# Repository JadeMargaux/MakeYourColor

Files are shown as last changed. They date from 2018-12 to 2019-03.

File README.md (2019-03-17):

# MakeYourColor

Avec ce projet, nous cherchons à automatiser et donc faciliter la préparation d’une palette de peinture, à l'aide d'une connexion Bluetooth et d'une LED informative. 

Dans l’idéal notre projet est de proposer deux possibilités pour le choix des couleurs : 

•	D’une part via des boutons prédéfinis correspondant à des couleurs précises.

•	D’autre part à l’aide de trois curseurs pour permettre à l’utilisateur une couleur sur mesure. 
 
Ce projet est destiné à un public particulier, comme des écoles maternelles ou des centres aérés.

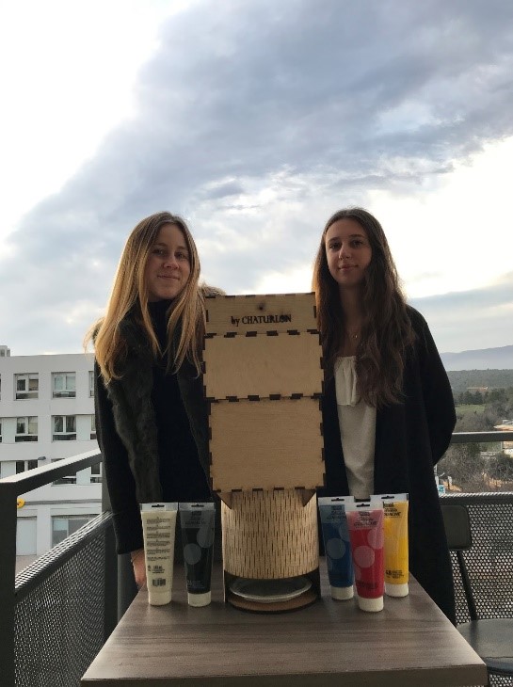
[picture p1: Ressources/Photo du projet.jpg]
Photo du projet


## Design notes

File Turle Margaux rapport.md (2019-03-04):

Turle Margaux                                               

Rapport

Séance 1 : 10 Décembre 2018    

Lors de cette première séance, nous avons commencé par créer un compte github. Nous avons ensuite écrit notre cahier des charges afin de 
définir notre projet (make your color), ainsi que le matériel que nous allons utiliser pour sa réalisation et la répartition des tâches.

De mon côté, j'ai fait sur excel un diagramme de gantt afin de prévoir les tâches à réaliser lors de chaque séance, ce qui est 
nécessaire à l'avancée du projet. 

Diagramme de Gantt

Séance 2 : 17 Décembre 2018

Aujourd'hui, j'ai réalisé le schéma de notre projet afin d'avoir une idée des différentes pièces à modéliser sur inventor. Pour cela, j'ai mesuré toutes les pièces (pipette, moteur). Dans le socle, je vais donc effectuer 5 trous de 4.5 cm de diamètre (diamètre correspondant à celui de la pipette). Notre socle mesurera 20 cm de diamètre et 46.5 cm de hauteur. En bas du socle, je vais faire un trou de largeur 5cm et d'une longueur d'un peu moins de la moitié du périmètre (environ 31cm) du cercle, soit 25 cm où nous allons placer la palette. En haut du socle, je ferais un petit trou dans lequel la barrette avec les dents pourra sortir.
Au dessus de chaque pipette, on aura un moteur avec une roue dentelée et une barrette avec des dents, ce qui permettra de pousser la peinture vers le bas. Il faudra donc modéliser 5 roues et 5 barrettes sur inventor et chercher s'il y a des plans déjâ réalisés sur internet.

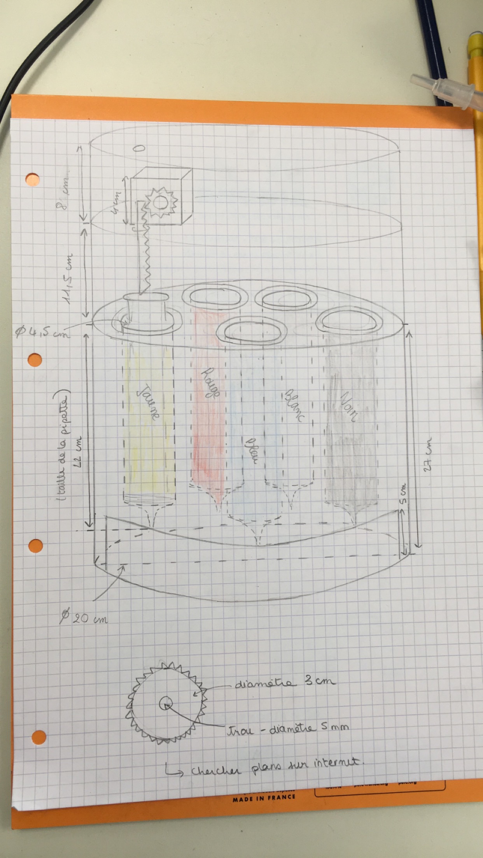
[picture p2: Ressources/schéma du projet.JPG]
Schéma du projet


Séance 3 : 07 Janvier 2019

Aujourd'hui, suite à votre demande, j'ai modifié le diagramme de gantt. En effet, j'ai précisé sur celui-ci notre rôle dans chacune des tâches à réaliser (voir légende).

Ensuite, je me suis intéressée aux différents liens que M.Masson nous a envoyé par mail afin de choisir la forme de la crémaillère. Nous allons en prendre une déjà toute faîte, ce qui est donc la solution la plus simple, qui va nous faire gagner du temps. https://www.stlfinder.com/model/linear-paintbrush-mechanism-nema17-bazykZqV/8073680

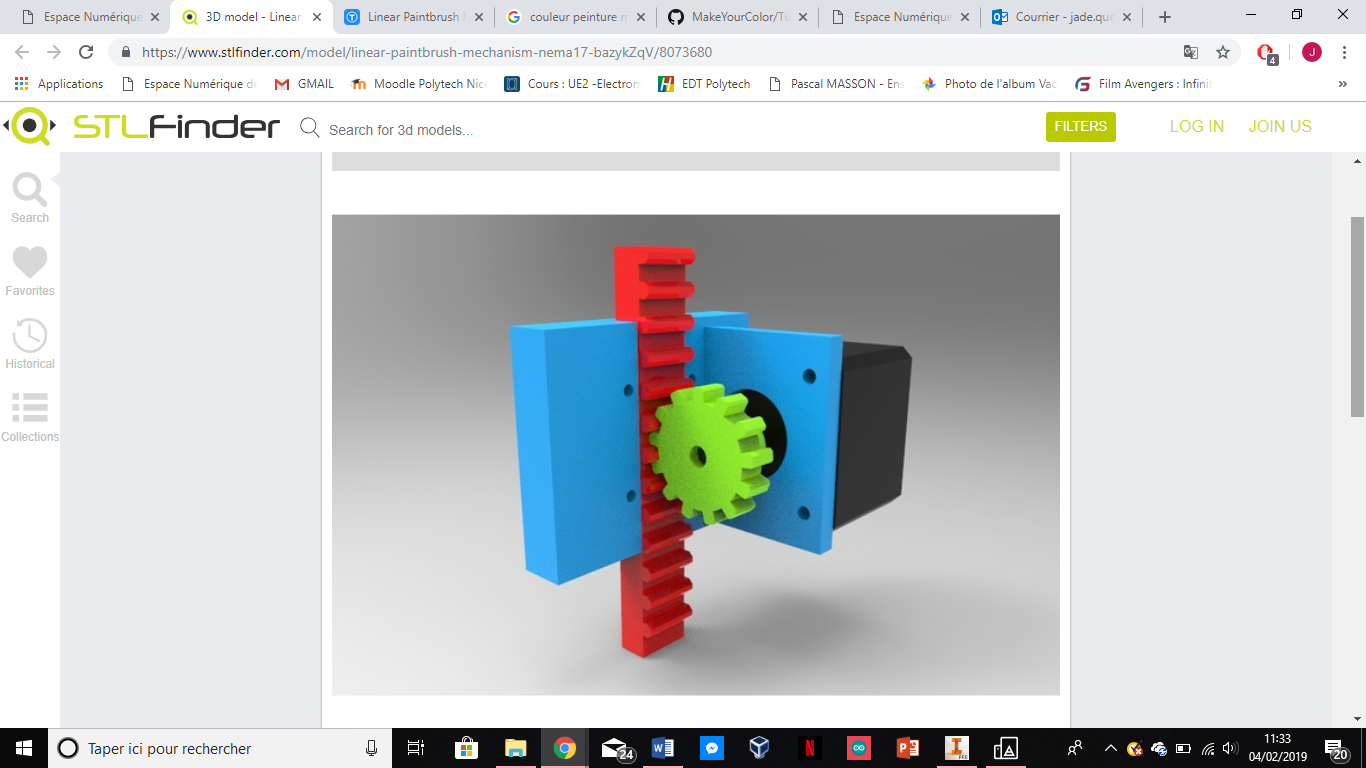
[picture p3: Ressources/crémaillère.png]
crémaillère


Enfin, sur inventor, j'ai commencé à modéliser la pièce centrale du projet, où j'ai percé les différents trous. Je finirai donc la semaine prochaine de modéliser les pièces restantes.

De plus, j'ai aidé jade à faire la soudure des moteurs, en tenant les fils afin que ce soit plus simple pour elle de souder et en dénudant les fils.

Séance 4 : 14 Janvier 2019

Aujourd'hui, j'ai dénudé les fils, et je les ai tenus pour la soudure du dernier moteur.
J'ai fini de modéliser les deux premières pièces de notre projet sur inventor, que vous pouvez voir ci-dessous. Il me restera donc à modéliser la dernière pièce puis à les imprimer en 3D, et les coller.
De plus, j'ai aidé jade à savoir si les moteurs tournaient lorsqu'elle appuyait sur les boutons via le téléphone portable.
Oral de fin de séance.

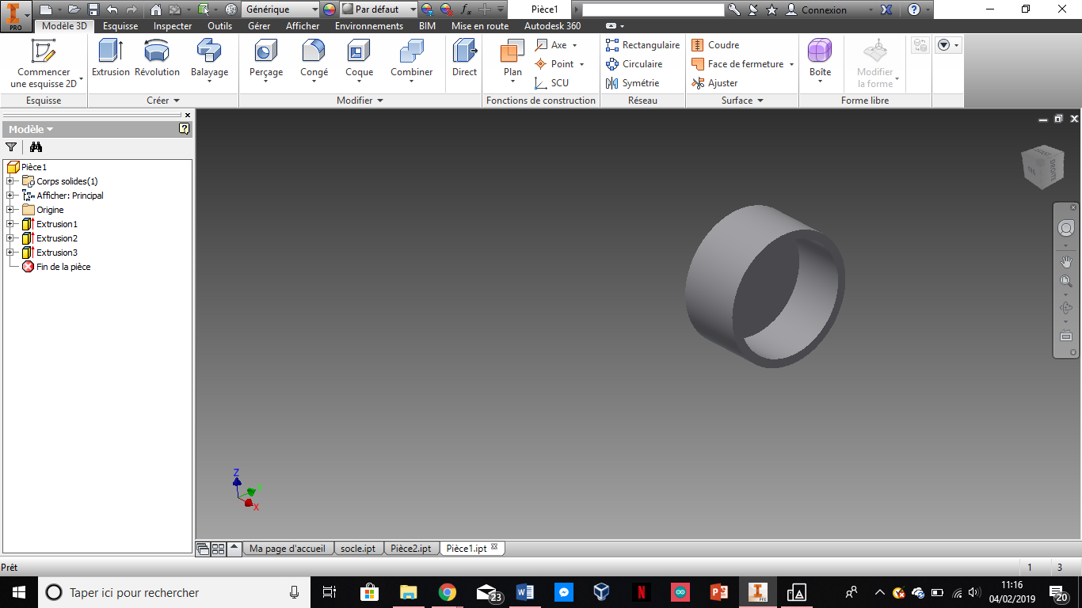
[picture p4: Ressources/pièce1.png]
pièce 1


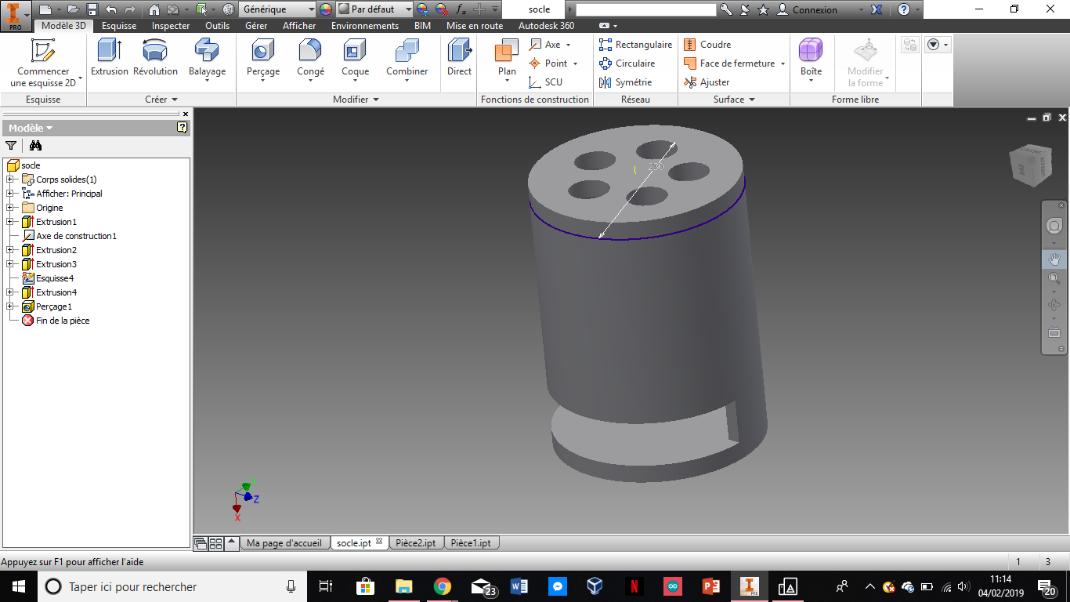
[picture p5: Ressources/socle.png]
socle

                                                                                               
                                                                                         

Séance 5 : 04 Février 2019

Aujourd'hui, nous avons réalisé la soudure du dernier moteur.
J'ai recherché sur internet une palette de couleurs plus complète que nous allons faire à partir des couleurs que nous avons déjà créées.

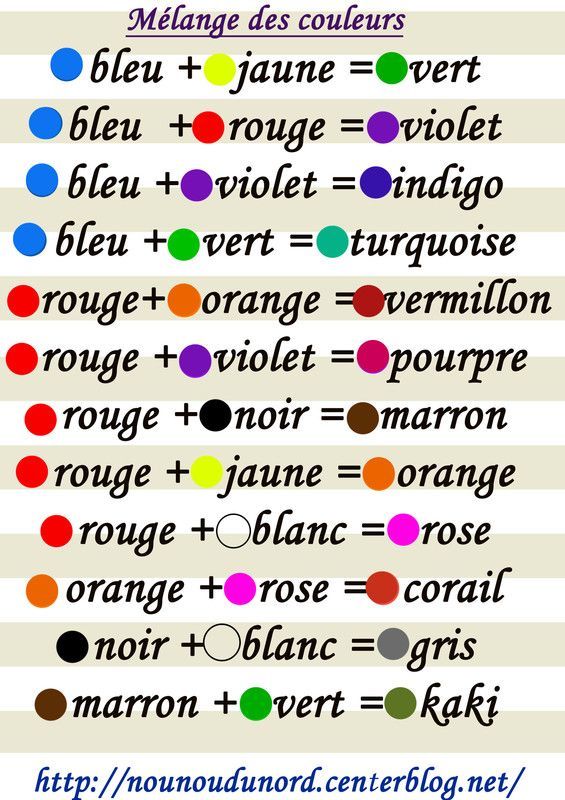
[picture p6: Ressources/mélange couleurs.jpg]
mélanges couleurs


Ensuite, j'ai modélisé sur inventor, la dernière pièce (celle du dessus), que vous pouvez voir ci-dessous

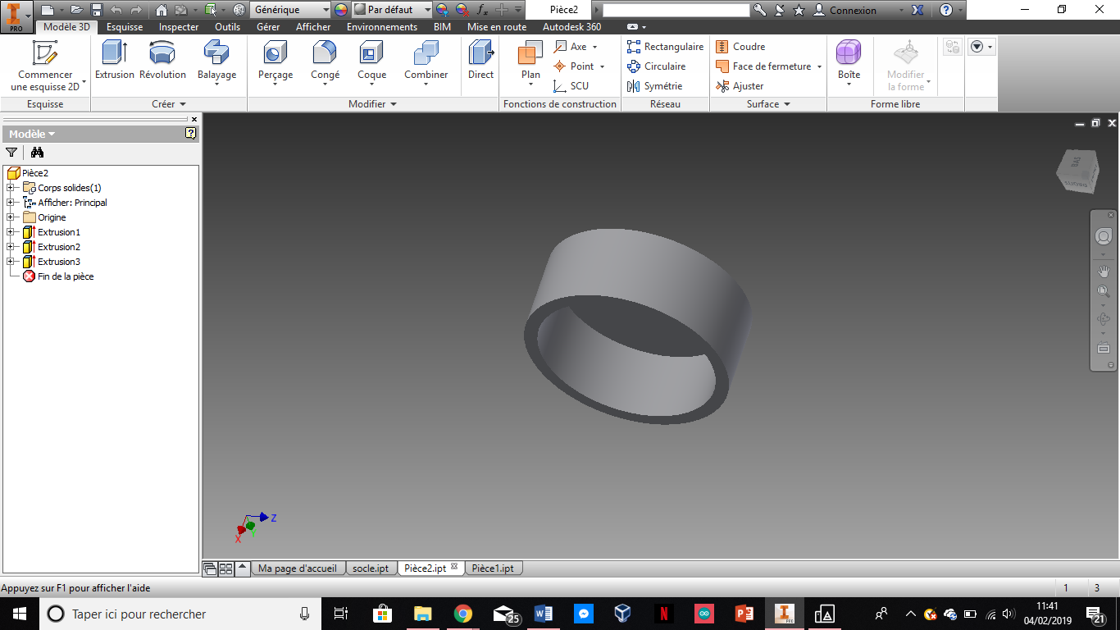
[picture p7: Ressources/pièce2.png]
pièce 2


Enfin, nous sommes allées au fablab afin d'imprimer les différentes pièces que j'ai modéliser.
Malheureusement, étant donné que notre socle ait une hauteur de 27cm, ceci est beaucoup trop grand pour l'imprimante 3D. Nous avons donc fait un choix entre imprimer le socle en 3D mais en deux fois et le coller ou faire notre socle en bois et découper les différentes pièces à l'aide du laser. Nous avons choisi, avec les conseils de la personne en charge du fablab d'avoir un socle en bois. Or, il faut savoir que pour découper les pièces de bois, il faut des plans en 2D alors que j'avais déjà réalisé tous les plans en 3D. J'ai donc redessiner les différents plans en 2D que nous avons refait sur le logiciel inscape. 

Jeudi 07 Février 2019

Nous avons réalisé puis découpé au laser un grand rectangle de 27 cm de hauteur et 62.8cm de largeur, avec plusieurs striures pour coller ses deux extrémités afin de former un cylindre. Au premier essai, les colonnes avec les différents traits pour les striures étaient espacées de 1.6cm ce qui était beaucoup trop grand pour pouvoir "plier" le bois. Au deuxième essai, nous avons donc espacé les colonnes d'environ 4mm, ce qui nous a permis de bien relier les deux extrémités du rectangle (45min de découpe). Ensuite, nous avons découper deux cercles de diamètre 188mm : le premier étant le socle sur lequel nous allons positionner le cylindre et le deuxième cercle, lui-même composé de cinq cercles pour y mettre les cinq seringues. (Au premier essai de découpe de cercle, nous avions découpé un cercle de 192mm, ce qui était beaucoup trop grand par rapport à la base de notre cylindre. Nous avions donc calculer l'écart entre les deux extrémités du rectangle lorsque nous essayions de les relier : 1.5cm, que nous avons retiré au périmètre du cercle du cylindre que nous avions tracé sur une feuille, afin de calculer le nouveau diamètre). Finalement nous avons collé la partie supérieur du cylindre avec le rectangle, que nous avons accroché avec l'aide d'une sangle.

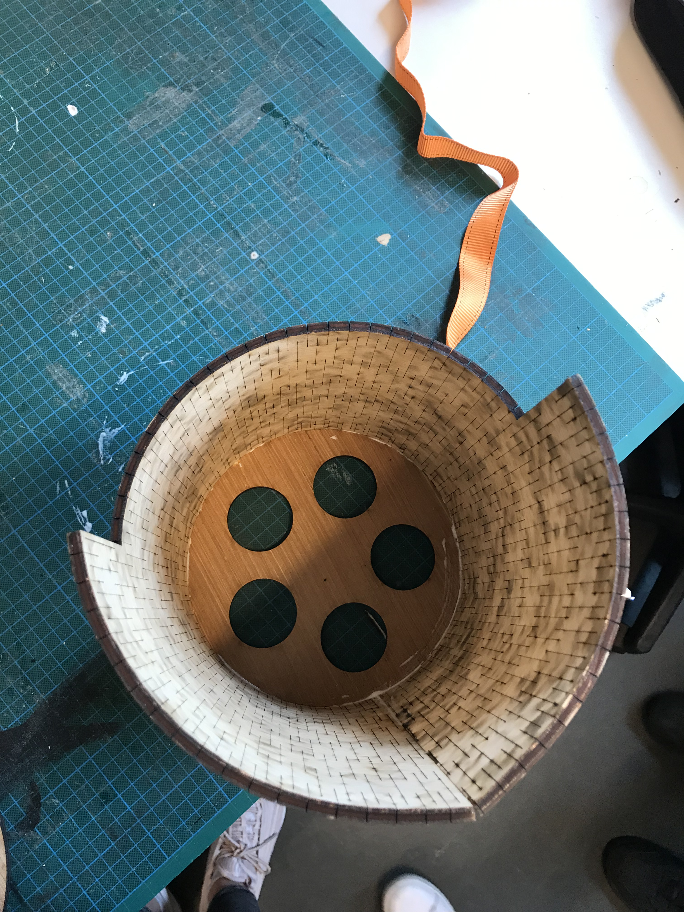
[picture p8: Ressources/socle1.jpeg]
photo collage1


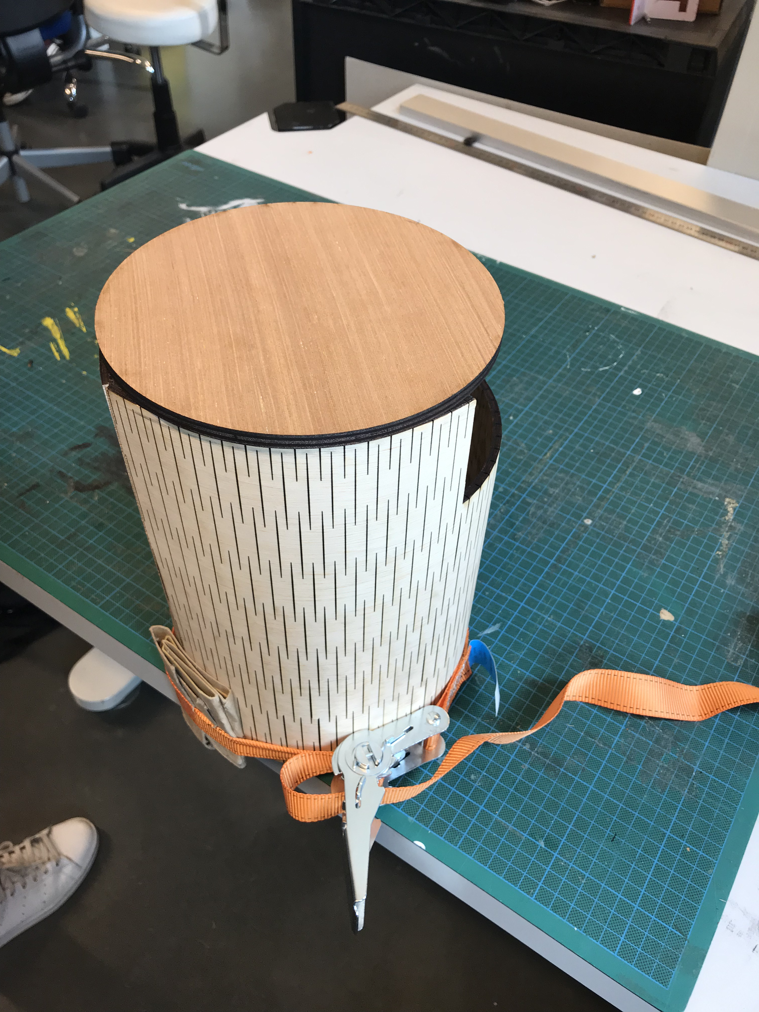
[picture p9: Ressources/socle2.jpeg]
photo collage2


Vendredi 08 Février 2019

Aujourd'hui, nous sommes allées au fablab. J'ai redessiné les plans de notre projet car nous nous sommes rendues compte que le schéma de base n'était pas pratique car, du fait que les trois cylindres soient collés, nous ne pouvions pas recharger la peinture dans les seringues. Nous avons donc décidé d'améliorer ce point. Pour cela, nous avons choisi de faire un cube, avec un trou d'un diamètre un plus grand que le cylindre pour qu'ils puissent s'emboiter. Nous allons faire tenir le cube avec des sortes d'equerres de fixation, sur lequel celui sera posé. On pourra donc enlever le cube du cylindre pour prendre les seringues et les recharger lorqu'elles sont vides.

Modélisation de la boîte grâce à :
http://carrefour-numerique.cite-sciences.fr/fablab/wiki/doku.php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

Après avoir refait le schéma du projet, nous avons collé la partie inférieur du cylindre. Ensuite, nous avons découpé les 6 faces du cube à la découpeuse laser, dans une des faces, nous avons découpé un cercle d'un diamètre un peu plus grand que celui du cylindre.
Enfin, nous avons collé les différentes faces du cube.

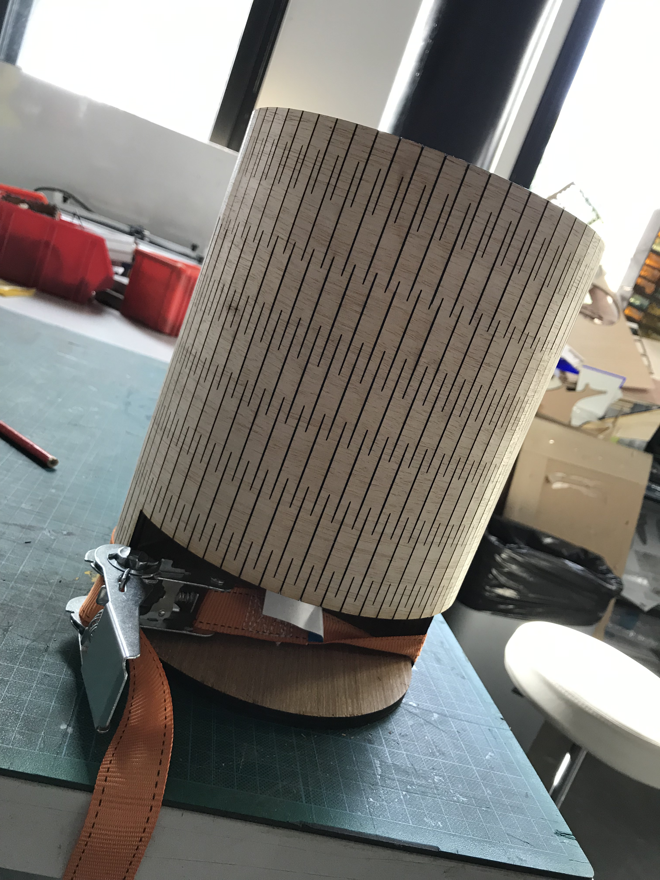
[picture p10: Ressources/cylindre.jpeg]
cylindre


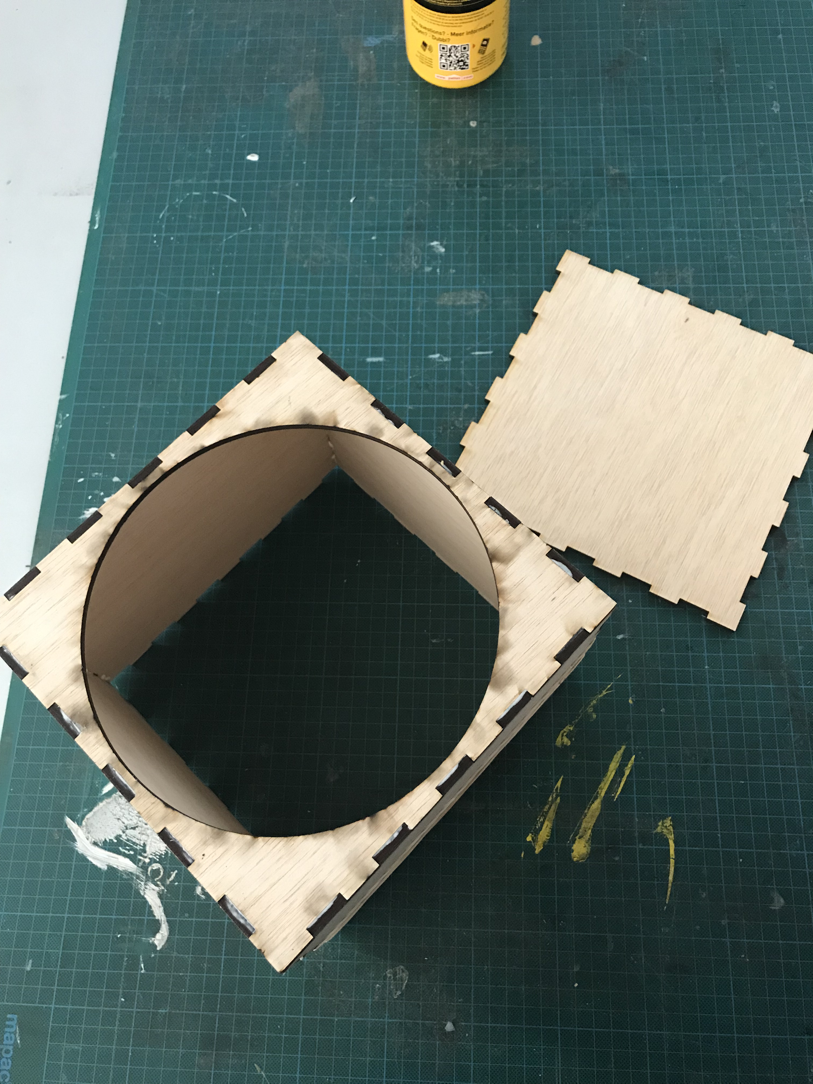
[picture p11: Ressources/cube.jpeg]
cube


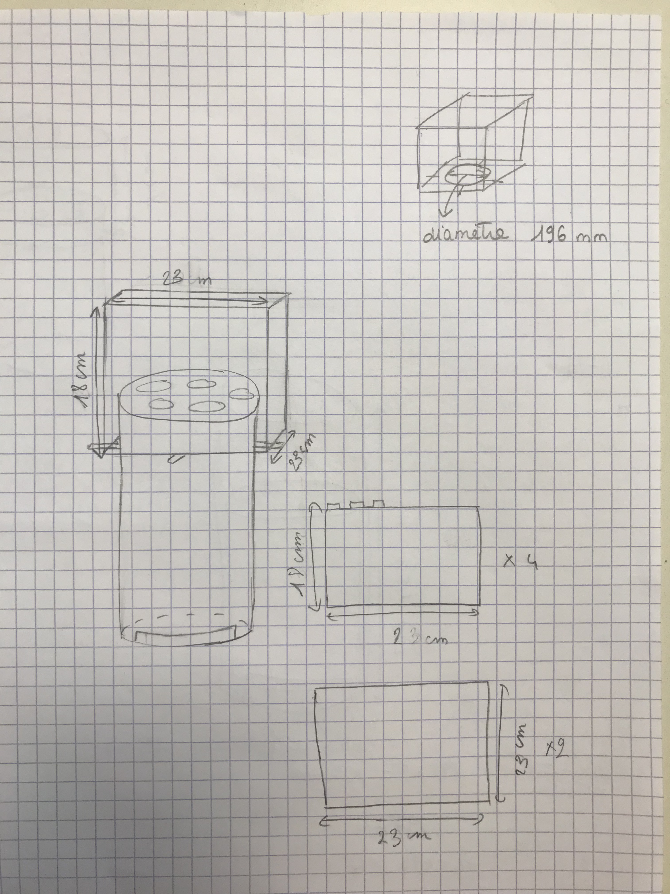
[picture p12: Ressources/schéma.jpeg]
schéma


Séance 6 : 11 Février 2019

J'ai recherché et j'ai trouvé, sur ebay, les peintures que nous allons utiliser. Il s'agit de 5 tubes de gouaches de 220ml (les couleurs primaires : rouge, bleu et jaune et noir et blanc).
Nous sommes allés au fablab pour faire à la découpeuse la partie supérieure de notre projet. Il sagit d'un parallélépipède où nous fixerons par la suite les moteurs. De plus nous avons découpé au laser 4 petites équerres que nous avons collés sur le cylindre. Ces équerres permettront de faire tenir la boite sur le cylindre. Cette boîte ne sera pas collée sur les équerres afin de pouvoir la retirer pour prendre seringues et les remplir lorsqu'elles seront vides.

La prochaine fois que nous irons au fablab, il faudra s'occuper des engrenages.

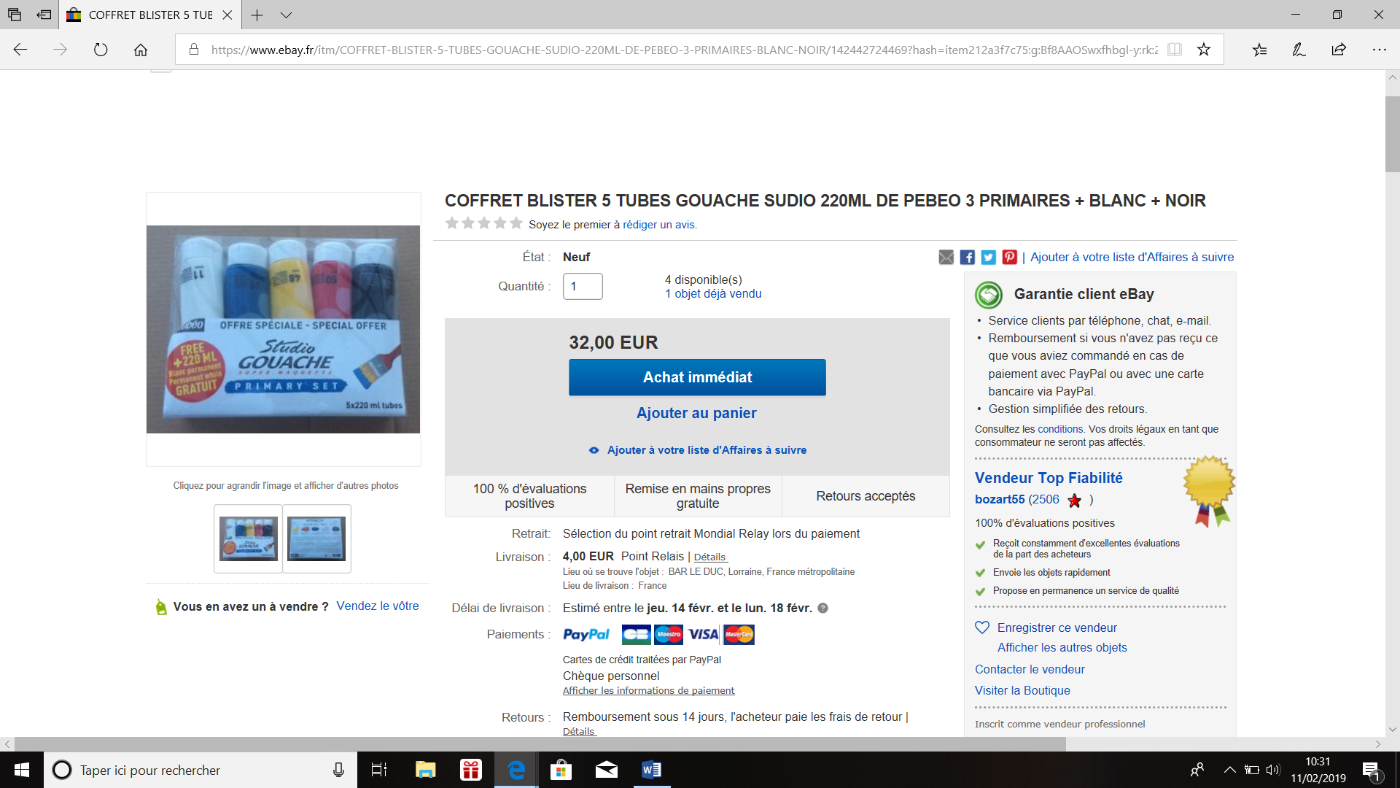
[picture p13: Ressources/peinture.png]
commande

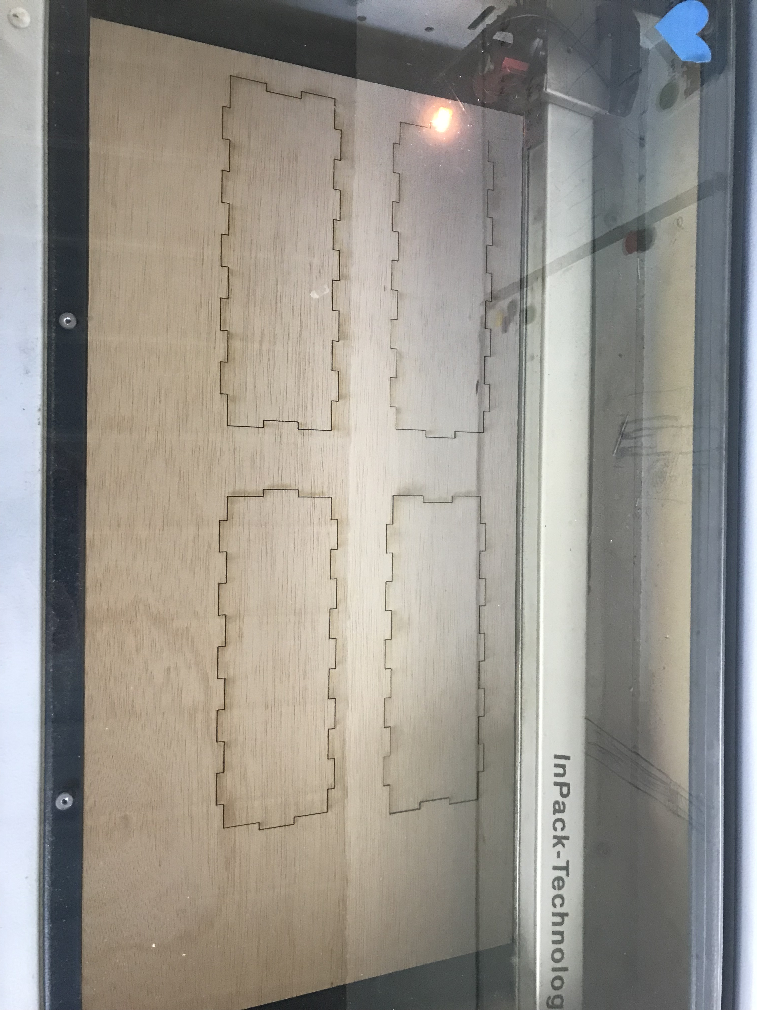
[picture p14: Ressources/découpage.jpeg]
découpage

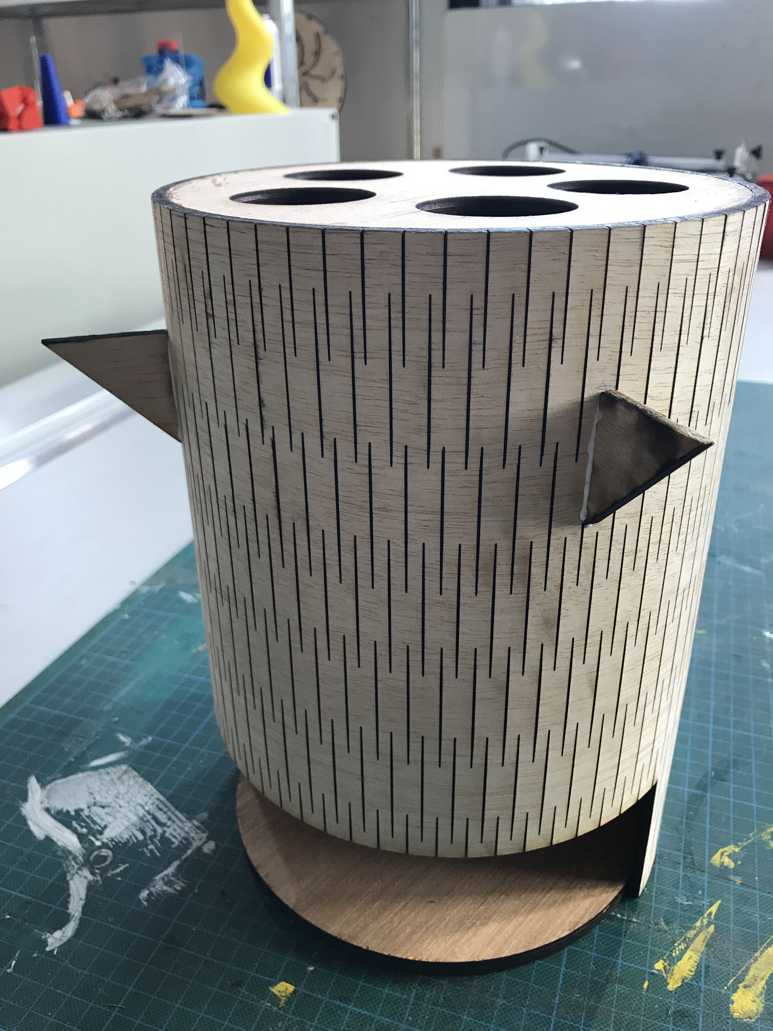
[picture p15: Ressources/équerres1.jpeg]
équerres

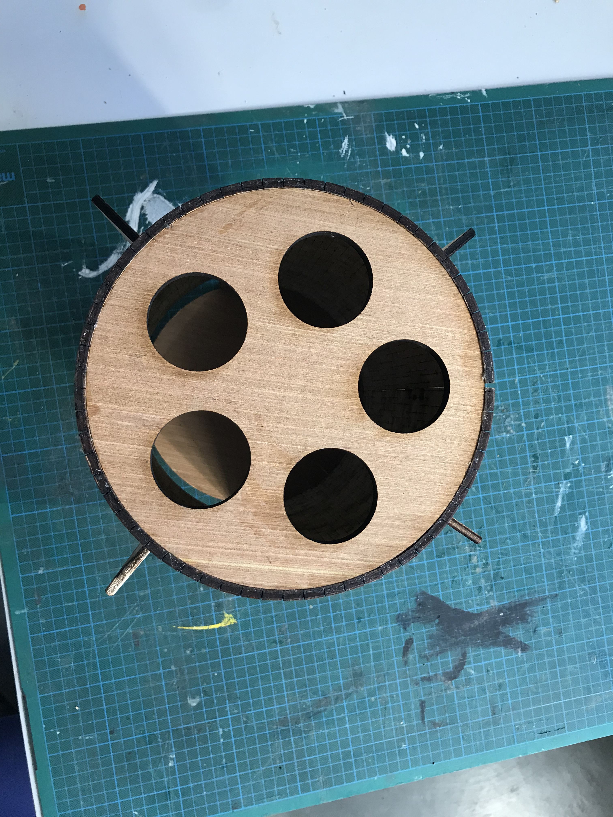
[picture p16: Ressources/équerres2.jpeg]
équerres


Séance 7 : 25 Février 2019

Aujourd'hui, j'ai travaillé avec jade sur le codage. En effet, nous avons réussi avec l'aide de Mr. Masson, à faire en sorte que la led s'allume en fonction de la couleur choisie par les curseurs rouge vert et bleu ou en fonction des boutons où nous avons déjà défini une couleur (orange, marron, rose, rouge, bleu, jaune, vert, noir, blanc, gris, violet). La couleur choisie par l'utilisateur sera ainsi visible sur la led. L'utilisateur pourra modifier sa couleur tant qu'il n'aura pas appuyé sur le bouton start. Il nous restera donc à faire le codage du bouton start pour valider le choix de l'utilisateur. De plus, nous avons vérifié si les bons moteurs tournaient lorsque nous appuyons sur la couleur correspondante. Cependant nous avons eu un problème puisque de la fumée est sortie des fils lorsque nous testions les moteurs. Puis, les moteurs ne marchaient plus.

Jeudi 28 Février 2019

Nous sommes allées au fablab pour imprimer en 3D la crémaillère. Sur ce que nous a envoyé Mr. Masson, les dimensions ne pouvaient pas être modifiés. Or la barette sur le site mesure 10cm et nous voulions une barette de 20 cm. Nous avons donc imprmer la barette de 10cm sur laquelle nous rajouterons une cale. Suite à la première impression (3h34), la barette était beaucoup trop large et ne pouvait pas glisser dans le dispositif prévu à cet effet. Nous avons donc mesuré l'écart entre le dispositif et la barette et nous avons réimprimer une barette à la bonne largeur. Celle-ci glissait alors correctement sur le montage. Il nous restera à imprimer les quatre autre crémaillères pour les quatre autres moteurs puis à les coller sur la structure. De plus, il nous restera à faire les cales. 

(14.7/15=0.98mm)

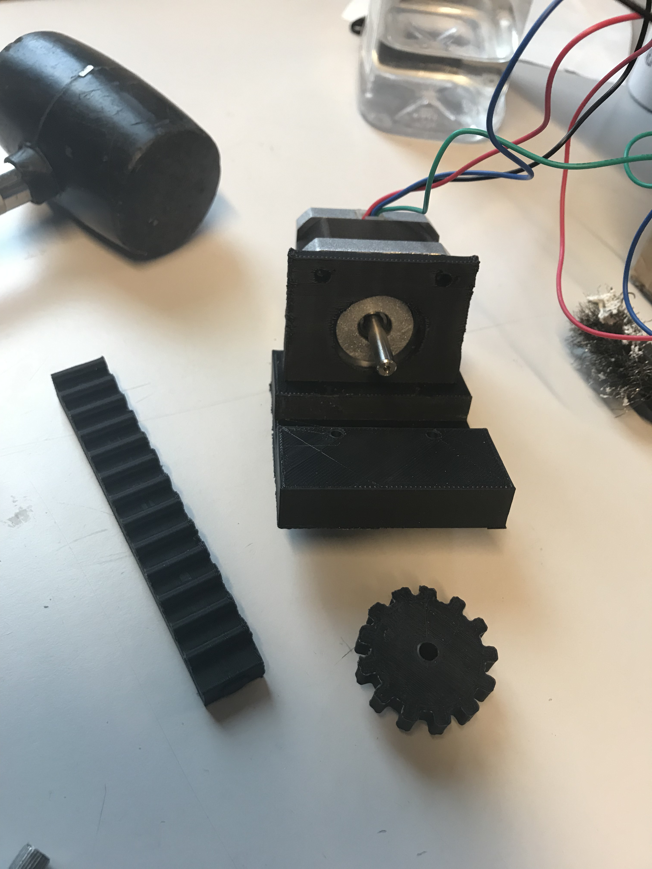
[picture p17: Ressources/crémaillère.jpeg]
crémaillère


Séance 8 : 04 Mars 2019

Nous avons dû avec l'aide de Mr. Masson vérifier si tous les moteurs tournaient correctement suite au court-circuit de la semaine précédente. De plus nous avons fini le programme concernant la led, qui s'allume en fonction des boutons ou des curseurs. Il nous reste par conséquent à faire le programme du bouton start et à trouver une solution pour passer des couleurs des curseurs en RGB (synthèse additive) aux couleurs primaires en peinture (rouge, jaune, bleu), ce qui est plutôt compliqué.

Recherche:
http://comment-peindre.com/couleurs-primaires-pour-debuter/

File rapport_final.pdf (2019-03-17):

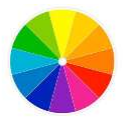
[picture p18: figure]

Ecole Polytechnique Universitaire de Nice Sophia-Antipolis, Département électronique

1645 route des Lucioles, Parc de Sophia Antipolis, 06410 BIOT

## PROJET Arduino - Peip2

### Année scolaire 2018-2019

# Make your color

## Étudiants : Queffeulou Jade Turle Margaux

## Encadrant : Masson Pascal

Ecole Polytechnique Universitaire de Nice Sophia-Antipolis, Département électronique

## Remerciements

Nous tenons à remercier dans un premier temps, l’équipe pédagogique de Polytech Nice-Sophia et les intervenants professionnels responsables de la formation de deuxième année de Peip, pour avoir assuré la partie théorique en amont du projet.

Nous remercions Monsieur Masson, professeur d’électronique et son stagiaire, pour l’aide et les conseils concernant les missions évoquées dans ce rapport qu’ils nous ont apporté lors des différentes étapes du projet.

En dernier lieu, nos remerciements vont à Monsieur Marc Forner, fabManager, qui a été présent tout au long de la conception de notre structure et nous a particulièrement aidé pour l’impression des pièces.

Ecole Polytechnique Universitaire de Nice Sophia-Antipolis, Département électronique

### Sommaire

II- Présentation du matériel | 6-7
III.2 Partie construction | 9-10

Ecole Polytechnique Universitaire de Nice Sophia-Antipolis, Département électronique

Introduction

Avec ce projet, nous cherchons à automatiser et donc faciliter la préparation d’une palette de peinture.

L’idée est de mettre en place un distributeur de peinture. La peinture est contenue dans des seringues. Pour ce projet, cinq seringues sont nécessaires. Elles correspondent aux trois couleurs primaires : rouge, bleu et jaune ainsi que le noir et le blanc. Le distributeur permet également de créer de nouvelles couleurs à l’aide des couleurs contenues dans lesdites seringues. Tout cela contrôlable depuis une application mobile connectée par Bluetooth. Le choix de ce module permet à l’utilisateur de se connecter facilement à la machine.

Dans l’idéal notre projet est de proposer deux possibilités pour le choix des couleurs :
- D’une part via des boutons prédéfinis correspondant à des couleurs précises.
- D’autre part à l’aide de trois curseurs pour permettre à l’utilisateur une couleur sur mesure.

Ce projet est destiné à un public particulier, comme des écoles maternelles ou des centres aérés.

Ecole Polytechnique Universitaire de Nice Sophia-Antipolis, Département électronique

I- Objectifs

I.1- Objectifs initiaux

Notre projet a pour but de créer différentes couleurs à l’aide de moteurs sur lesquels sera fixée une roue dentelée. Lorsque les moteurs seront en marche, ils feront tourner la roue qui va elle-même faire coulisser une crémaillère. Cette crémaillère va pousser sur les seringues, ce qui va faire tomber la peinture sur la palette et créer une nouvelle couleur.
Les moteurs seront eux-mêmes actionnés grâce au module Bluetooth par différents boutons qui définissent une couleur particulière, présents sur l’application mobile.

Ces boutons pourront actionner les couleurs suivantes :
- orange (mélange de rouge et de jaune)
- violet (mélange de bleu et de rouge)
- vert (mélange de jaune et bleu)
- marron (mélange de rouge, jaune et bleu)
- rose (rouge et blanc)
- gris (noir et blanc)

Ainsi que les couleurs déjà présentes dans les seringues :
- rouge
- jaune
- bleu
- noir
- blanc

De plus, initialement, le projet avait également pour but d’éclaircir (respectivement assombrir) les couleurs, en ajoutant au mélange la couleur blanche (respectivement noire).

Ecole Polytechnique Universitaire de Nice Sophia-Antipolis, Département électronique

I.2 Objectifs atteints

Finalement, nous avons abandonné l’idée d’éclaircir ou d’assombrir les couleurs en y ajoutant du blanc ou du noir. Il suffira simplement d’appuyer de nouveau sur le bouton blanc pour éclaircir ou noir pour assombrir.

En plus des boutons correspondants à des couleurs particulières, l’application sera constituée de trois curseurs : cyan, magenta et jaune.
Ces curseurs permettant alors à l’utilisateur de créer sa propre couleur. Cette couleur ainsi créée pourra être visible sur une LED et modifiable tant que l’utilisateur n’aura pas appuyé sur le bouton start.

De plus, par soucis de praticité, la forme de la structure n’est plus la même que sur le schéma initial (cf annexe).

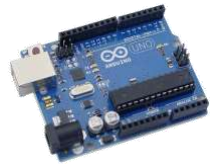
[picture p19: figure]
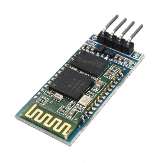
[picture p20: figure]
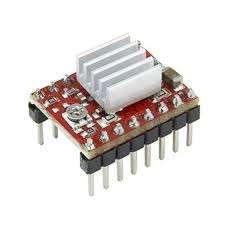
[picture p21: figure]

Ecole Polytechnique Universitaire de Nice Sophia-Antipolis, Département électronique

II- Présentation du matériel

Carte Arduino
ATmega328PB
Xplained mini

⇨ Gère l’ensemble de
l’électronique

Moteur pas à pas
Nema 17

⇨ Fait tourner la roue dentelée

Driver A4988
avec radiateur

⇨ Contrôle le moteur pas-à-pas

Module Bluetooth HC-06

⇨ Permet la connexion Bluetooth avec l’application “Bluetooth Electronics” sous Android

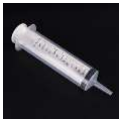
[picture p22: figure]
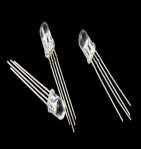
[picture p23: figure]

Ecole Polytechnique Universitaire de Nice Sophia-Antipolis, Département électronique

Seringue 150 ml

⇨ Contient la peinture

LED RGB branchée en anode

⇨ informer l’utilisateur de la couleur créée

Condensateur électrolytique bleu isolé

⇨ permet de lisser la tension

Ecole Polytechnique Universitaire de Nice Sophia-Antipolis, Département électronique

III- Réalisation

III.1 Partie code

La partie code du projet se décompose en plusieurs codes distincts.

La première étape est la connexion avec le module Bluetooth : il y a un code qui permet à l’utilisateur de se connecter via le module Bluetooth HC-06 à l’application “Bluetooth Electronics” du mobile. Il faut alors que l’utilisateur tape les commandes AT+Namenom et AT+PINpin sur le moniteur série pour pouvoir se créer un identifiant pour la toute première fois. Cette connexion ayant été préalablement faite, l’utilisateur n’a plus qu’à, chaque fois, se reconnecter avec le même identifiant sur l’application.

La deuxième étape est le choix de la couleur personnalisée :

Dans ce cas, la carte Arduino est en dialogue avec le module Bluetooth.
Les trois curseurs ; cyan, magenta et jaune ainsi que les boutons sont définis à l’aide de la fonction Switch(). En effet, les trois curseurs et les onze boutons correspondant à une couleur déjà définie sont associés à des lettres différentes. Lorsque la lettre correspondant à une couleur est envoyée à la carte Arduino, cette couleur est alors visible sur la LED.

Ainsi, sur l’application, l’utilisateur peut créer sa propre couleur avec les curseurs en la visualisant sur la LED RGB. Ce processus se fait via la fréquence du PWM qui est envoyé par l’application Bluetooth. Cette fréquence prend des valeurs entières allant de 0 à 255 et suivant la valeur de la fréquence PWM la couleur diffère.

La dernière étape correspond au fonctionnement des moteurs :

Une fois la couleur réalisée par l’utilisateur, il peut la valider grâce au bouton START présent également sur l’application. Ce bouton est lui aussi relié à une lettre. Son utilisation permet aux moteurs correspondants de se mettre en marche. En effet, chaque couleur créée correspond à trois valeurs de PWM différentes en simultanée. Par exemple le rouge à pour valeurs (0,255,0). Ces trois valeurs correspondent aux trois couleurs que sont le cyan, magenta et jaune. Ainsi les valeurs du PWM de la couleur entraîne le fonctionnement des moteurs dont le pas correspond à cette même valeur.

Ecole Polytechnique Universitaire de Nice Sophia-Antipolis, Département électronique

Pour pouvoir vérifier le fonctionnement de chaque élément, il y a deux codes de bases, extérieur au code final. Parmi ces 2 codes, on trouve : le code de rotation d’un moteur pas-à-pas, qui gère le fonctionnement d’un unique moteur, et le code de la LED RGB. Ce dernier a été nécessaire pour déterminer les bonnes valeurs du PWM à utiliser.

Les codes sont visibles dans la partie Annexes.

III.2 Partie construction

Toute la partie construction de la structure s’est déroulée au fablab de Polytech Nice Sophia grâce à la découpeuse laser et l’imprimante 3D.

Nous avons construit l’intégralité de notre structure. Celle-ci se compose en quatre parties principales :

La partie inférieure, de forme cylindrique.
La réalisation de ce cylindre s’est faîte à partir : d’un grand rectangle de bois de 27 cm de hauteur et 62.8 cm de largeur, striés, afin de pouvoir lui donner de la souplesse et coller les deux extrémités, ainsi que de deux cercles. Ces deux cercles ont pour diamètre 188mm : le premier étant le socle sur lequel nous allons positionner le cylindre et le deuxième est lui-même composé de cinq cercles pour y mettre les cinq seringues. Le tout collé et maintenu pendant un certain temps avec une sangle.

La partie centrale, une boîte.
Ce cube est composé de quatre rectangles de longueur 18 cm et de largeur 23 cm ainsi que deux carrés de largeur 23 cm. La face inférieure de la boîte possède un trou d'un diamètre un peu plus grand que celui du cylindre pour qu'ils puissent s'emboîter. Ainsi, on pourra retirer la partie supérieure de la structure pour retirer les seringues du cylindre et les recharger lorsqu’elles sont vides. Tandis que la face supérieure possède 5 trous (de 2,3 cm x 4,5 cm) au-dessus de chaque piston afin de laisser passer la crémaillère.
Ce cube est donc emboîté et tient sur la partie inférieure grâce à des sortes d'équerres de fixation, sur lequel celui-ci sera posé.

Puis, au-dessus de cette boîte, il y a une seconde boîte composée de quatre rectangles de mesure 12,5 cm x 23,5 cm et de deux carrés de longueur 23,5 cm.

Ecole Polytechnique Universitaire de Nice Sophia-Antipolis, Département électronique

C’est à l’intérieur de cette boîte que sont fixés les cinq moteurs au-dessus des cinq seringues avec du scotch double face. Afin que les crémaillères puissent pousser les pistons et ainsi faire tomber la peinture dans la palette, il y a cinq trous de 2,3 cm x 4,5 cm sur la face inférieure. De plus, sur la face supérieure, il y également cinq trous de même dimension que précédemment pour faire passer les fils vers la partie supérieure de la structure.

La partie supérieure, une troisième boîte.
Cette boîte mesure 8 cm x 23 cm x 23 cm. La face inférieure possède aussi cinq trous (toujours de même dimension) afin de pouvoir connecter les moteurs à la plaque Arduino qui se trouve dans cette boîte. De plus, sur la face avant, nous avons écrit avec la découpeuse laser : “by CHATURLON” et nous avons découpé un trou au-dessus afin que la LED puisse être visible des utilisateurs.

En dernier lieu, l’imprimante 3D nous a permis d’imprimer le mécanisme composé du support du moteur ainsi que la crémaillère et la roue dentelée afin de faire fonctionner l’ensemble.

IV. Difficultés

IV.1 Partie code

Au début, le code était unique. Il permettait la rotation des moteurs lorsque l’utilisateur appuie sur les boutons prédéfinis. À la suite de la première présentation orale, le professeur a mis en avant la simplicité du projet. Ainsi, il a été décidé d’ajouter des curseurs pour la création de couleur personnalisées et une LED RGB pour visualiser la couleur choisie. Cette partie étant plus complexe, les premiers essais n’étaient pas fluctuants. En effet, la LED RGB branchée en anode donnait des couleurs cyan, magenta et jaune. Cela s’explique par le fait que les valeurs de la fréquence PWM sont en réalité inversées, c’est à dire que le(0,0,0) donne la couleur blanche tandis que le (225,255,255) donne la couleur noire. Il a donc fallu faire attention d’écrire les bonnes valeurs de PWM correspondantes dans le nouveau code. Cependant, après réflexions, la synthèse soustractive fournie par le cyan, magenta et jaune semble plus proche des couleurs primaires de la peinture que la synthèse additive fournie par le rouge, vert et bleu. Nous avons donc gardé les valeurs de base.

Ecole Polytechnique Universitaire de Nice Sophia-Antipolis, Département électronique

De plus, l’un des drivers A4988, est devenu défectueux. Les moteurs tournaient, enfin vibraient sans arrêt et le moteur connecté au driver ne tournait plus du tout. Cela produisait une sorte de court-circuit. Pendant les essais, il y avait une forte surchauffe. Il nous a donc fallu un nouveau driver. D’ailleurs, pour éviter encore plus une surchauffe des moteurs, nous avons défini l’entrée “enable” qui met les moteurs à l’arrêt quand ils ne sont pas utiles.

IV.2 Partie construction

Pour commencer, la structure était modélisée sur Inventor afin de l’imprimer en 3D, cependant pour des raisons de dimension, il n’était pas possible d’utiliser l’imprimante. En effet, la partie inférieure mesurant 27 cm de hauteur, ceci était beaucoup trop grand à imprimer. Finalement, pour palier à ce problème, nous avons décidé d’utiliser la découpeuse laser et ainsi d’avoir une structure en bois. Tous les plans ont donc été refait en 2D avec le logiciel Inkscape avec l’aide de la personne en charge du fablab.

Pour ce qui est de la partie inférieure, nous avons dû faire plusieurs stries sur le rectangle de bois afin de pouvoir le plier. Or, au premier essai, celles-ci étaient beaucoup trop écartées (1,6 cm), ce qui rendait impossible le pliage du bois. Au deuxième essai, l’écart choisi entre les stries était beaucoup plus petit (4 mm), ce qui nous a permis de bien relier les deux extrémités du rectangle.

Ensuite, le schéma de base n'étant pas pratique, du fait que les trois cylindres soient collés, la peinture dans les seringues ne pouvait pas être rechargée. Notre structure a dû être modifié. En effet, la structure finale ne correspond pas à celle sur le schéma initial. Au départ, celle-ci devait être un cylindre composé de trois parties cylindriques collées entre elles mais finalement, elle est composée d’un cylindre et de trois boîtes. Les trois boîtes sont collées entre elles et peuvent être retirées du cylindre afin de pouvoir prendre les seringues pour les recharger.

Enfin, pour l’impression 3D du mécanisme composé de la crémaillère et la roue dentelée, la longueur de la crémaillère était de 10 cm sur le site trouvé par Mr. Masson et il fallait que celle-ci mesure 20 cm. Nous avons donc gardé celle-ci, car par manque de temps, nous ne pouvions refaire les dimensions. De plus, suite à la première impression du mécanisme (d’une durée de 3h34), la

Ecole Polytechnique Universitaire de Nice Sophia-Antipolis, Département électronique crémaillère était beaucoup trop large et ne pouvait pas glisser dans le dispositif prévu à cet effet. Nous avons donc mesuré l'écart entre le dispositif et la crémaillère et nous l’avons réimprimé à la bonne largeur. Celle-ci glissait alors un peu mieux sur le montage. Cependant ce n’était pas suffisant pour un glissement optimal. En effet, nous avons dû limer la crémaillère ainsi que la roue dentelée car du fait que l’impression 3D n’était pas parfaite, il y avait trop de frottement ce qui empêchait les moteurs de tourner correctement. D’autre part, les trous pour les vis sur le support et le trou central pour faire passer la tige du moteur étaient trop petit donc il a fallu repercer tous les trous de chaque moteur, ce qui nous a pris du temps.

Ecole Polytechnique Universitaire de Nice Sophia-Antipolis, Département électronique

Conclusion

Bilan final du projet : Make your color or not ?

A ce stade, notre projet a partiellement atteint les objectifs que nous avions fixé, même si certains ont été modifié en cours de route.

En résumé, l’utilisateur choisit la couleur qu’il souhaite sur le téléphone grâce aux boutons prédéfinis ou aux curseurs, et la valide grâce au bouton START. Cette couleur est visible à tout moment sur la LED. Le téléphone, lui, est connecté à l’Arduino via un module Bluetooth. Puis il n’a plus qu'à attendre que la peinture contenue dans les seringues coule sur la palette.

C’est une machine qui se veut être pratique, rapide et surtout utile pour les inconnus des couleurs.

D’une part, les difficultés que nous avons rencontrées, ont été en quelque sorte bénéfiques car elles ont permis de rendre la machine plus fonctionnelle. En effet, notre schéma de base n’aurait servi que pour une seule fois. Cependant, à cause de certains problèmes rencontrés, et d’un manque de temps, les tests avec la peinture n’ont pas été réalisés.

Ressenti vis à vis de ce projet :

Nous avions l’habitude de réaliser des exposés ou des présentations sur un sujet précis cependant le fait de créer un projet entièrement, de l’idée à la conception était nouveau pour nous (mis à part le TPE de 1ère).
Les compétences acquises au cours des TD ont pu être utilisées à bon escient. Imaginer un projet, le mettre en oeuvre, palier aux problèmes et pouvoir l’améliorer est une expérience enrichissante.

Ecole Polytechnique Universitaire de Nice Sophia-Antipolis, Département électronique

Ressources

https://www.stlfinder.com/model/linear-paintbrush-mechanism-nema17-bazykZqV/8073680 (https://www.stlfinder.com/model/linear-paintbrush-mechanism-nema17-bazykZqV/8073680)

http://carrefour-numerique.cite-sciences.fr/fablab/wiki/doku.php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 (http://carrefour-numerique.cite-sciences.fr/fablab/wiki/doku.php)

https://www.ebay.fr/itm/COFFRET-BLISTER-5-TUBES-GOUACHE-SUDIO-220ML-DE-PEBEO-3-PRIMAIRES-BLANC-NOIR/142442724469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 (https://www.ebay.fr/itm/COFFRET-BLISTER-5-TUBES-GOUACHE-SUDIO-220ML-DE-PEBEO-3-PRIMAIRES-BLANC-NOIR/142442724469)

https://www.arduino.cc/reference/en/language/structure/control-structure/switchcase/ (https://www.arduino.cc/reference/en/language/structure/control-structure/switchcase/)

http://users.polytech.unice.fr/~pmasson/Enseignement-arduino.htm

https://www.carnetdumaker.net/articles/utiliser-des-leds-rgb-avec-une-carte-arduino-genuino/ (https://www.carnetdumaker.net/articles/utiliser-des-leds-rgb-avec-une-carte-arduino-genuino/)

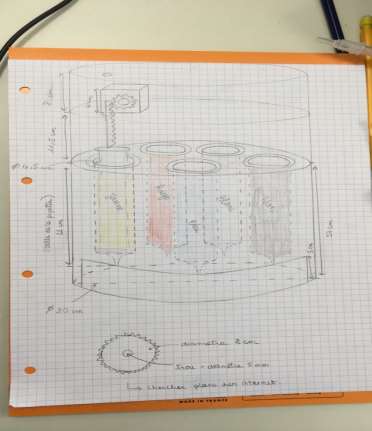
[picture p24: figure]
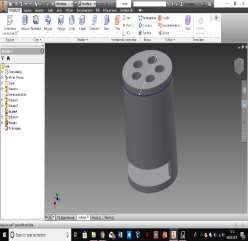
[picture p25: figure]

Ecole Polytechnique Universitaire de Nice Sophia-Antipolis, Département électronique

Annexes

Partie construction

Schéma initial

Partie inférieure


Ecole Polytechnique Universitaire de Nice Sophia-Antipolis, Département électronique

Partie intermédiaire

Partie supérieure

Collage du cylindre


Ecole Polytechnique Universitaire de Nice Sophia-Antipolis, Département électronique


Ecole Polytechnique Universitaire de Nice Sophia-Antipolis, Département électronique

Partie intermédiaire


Ecole Polytechnique Universitaire de Nice Sophia-Antipolis, Département électronique

Découpage partie supérieure


Ecole Polytechnique Universitaire de Nice Sophia-Antipolis, Département électronique

Collage des équerres


Ecole Polytechnique Universitaire de Nice Sophia-Antipolis, Département électronique

Limage des supports

Schéma final


Ecole Polytechnique Universitaire de Nice Sophia-Antipolis, Département électronique

Partie inférieure (cylindre et seringues)

Partie supérieure (3 boîtes)


Ecole Polytechnique Universitaire de Nice Sophia-Antipolis, Département électronique

Disposition des moteurs

Boîte pour la carte arduino


Ecole Polytechnique Universitaire de Nice Sophia-Antipolis, Département électronique

Structure finale

Photo de l’équipe avec le projet

Ecole Polytechnique Universitaire de Nice Sophia-Antipolis, Département électronique

Partie code

//Code pour la connexion de l’arduino au module Bluetooth

#include<SoftwareSerial.h>

#define RX 12//Pin 12 pour RX, à brancher sur le TX du HC-06 #define TX 13 //Pin 13 pour RX, à brancher sur le RX du HC-06

SoftwareSerial BlueT(RX,TX);

void setup() {
Serial.begin(9600);
delay(500);
Serial.println("Bonjour -Pret pour les commandes AT"); BlueT.begin(9600);
}
void loop() {
while (BlueT.available()) { Serial.print(char(BlueT.read())); } while (Serial.available()) { BlueT.write(char(Serial.read())); } }

//Code pour le test des moteurs

const int Pas5 = 16;
const int Dir5 = 15;
const int Pas4 = 14;
const int Dir4 = 8;
const int Pas3 = 7;
const int Dir3 = 6;
const int Pas2 = 5;
const int Dir2 = 4;
const int Pas1 = 3;
const int Dir1 = 2;
const int enable = 17;

void setup() {
Serial.begin(115200);
pinMode(enable, OUTPUT); //enable en sortie

Ecole Polytechnique Universitaire de Nice Sophia-Antipolis, Département électronique digitalWrite(enable, HIGH);
pinMode(Pas5, OUTPUT); //le moteur en sortie pinMode(Dir5, OUTPUT);
digitalWrite(Dir5, HIGH);
pinMode(Pas4, OUTPUT); //le moteur en sortie pinMode(Dir4, OUTPUT);
digitalWrite(Dir4, HIGH);
pinMode(Pas3, OUTPUT); //le moteur en sortie pinMode(Dir3, OUTPUT);
digitalWrite(Dir3, HIGH);
pinMode(Pas2, OUTPUT); //le moteur en sortie pinMode(Dir2, OUTPUT);
digitalWrite(Dir2, HIGH);
pinMode(Pas1, OUTPUT); //le moteur en sortie pinMode(Dir1, OUTPUT);
digitalWrite(Dir1, HIGH);
}
void loop() {

//*****************MOTEUR 2************ on test ici que le moteur 2 digitalWrite(enable, LOW);
for (int x = 200; x > 0; x--) {
Serial.println(x);
digitalWrite(Dir5, LOW);
digitalWrite(Pas5, HIGH);
delayMicroseconds(50);
digitalWrite(Pas5, LOW);
delay(4);}
digitalWrite(enable, HIGH); delay(500);

digitalWrite(enable, LOW); for (int x = 0; x < 200; x++) { Serial.println(x);
digitalWrite(Dir5, HIGH);
digitalWrite(Pas5, HIGH);
delayMicroseconds(50);
digitalWrite(Pas5, LOW);
delay(4);

Ecole Polytechnique Universitaire de Nice Sophia-Antipolis, Département électronique

}
digitalWrite(enable, HIGH); delay(500);
}

//Code pour le test de la LED

void setup() {
pinMode(9, OUTPUT);
digitalWrite(9,LOW);
}
void loop() {
}

// Code final dialogue avec le smartphone et fonctionnement des moteurs

#include<SoftwareSerial.h>

#define RX 12

#define TX 13

SoftwareSerial BlueT(RX,TX); int PWMC;
int PWMJ;
int PWMM;
int PWMN;
int PWMB;
char Data;
const int Pas1 =3; //moteur1 const int Dir1 =2; //moteur1 const int Pas2=5;//moteur2 const int Dir2=4;//moteur2 const int Pas3=7;//moteur3 const int Dir3=6;//moteur3 const int Pas4=14;//moteur4 const int Dir4=8;//moteur4 const int Pas5=16;//moteur5 const int Dir5=15;//moteur5 const int enable=17;

Ecole Polytechnique Universitaire de Nice Sophia-Antipolis, Département électronique const byte LED1 = 9; //rouge CYAN const byte LED2 = 10; //vert MAGENTA const byte LED3 = 11; //bleu JAUNE

void setup() {
Serial.begin(115200);
BlueT.begin(9600);
pinMode(enable,OUTPUT);
digitalWrite(enable,HIGH);

pinMode(Pas1,OUTPUT); //on initialise le moteur1, correspond à la couleur bleu
pinMode(Dir1,OUTPUT);
digitalWrite(Dir1,HIGH);

pinMode(Pas2,OUTPUT); //on initialise le moteur2, correspond à la couleur jaune
pinMode(Dir2,OUTPUT);
digitalWrite(Dir2,HIGH);
pinMode(Pas3,OUTPUT); //on initialise le moteur3, correspond à la couleur rouge
pinMode(Dir3,OUTPUT);
digitalWrite(Dir3,HIGH);
pinMode(Pas4,OUTPUT); //on initialise le moteur4, correspond à la couleur blanche
pinMode(Dir4,OUTPUT);
digitalWrite(Dir4,HIGH);
pinMode(Pas5,OUTPUT);//on initialise le moteur5, correspond à la couleur noire
pinMode(Dir5,OUTPUT);
digitalWrite(Dir5,HIGH);
pinMode(LED1, OUTPUT); //on initialise la LED pinMode(LED2, OUTPUT);
pinMode(LED3, OUTPUT);
}

void loop() {

Ecole Polytechnique Universitaire de Nice Sophia-Antipolis, Département électronique if (BlueT.available()){ //dialogue avec le bluetooth Data=BlueT.read();
switch (Data){
case 'L': //cyan
PWMC=BlueT.parseInt();
break;

case 'T': //mangenta
PWMM=BlueT.parseInt();
break;

case 'K': //jaune
PWMJ=BlueT.parseInt();
break;

case 'O'://orange
PWMC=0;
PWMJ=255;
PWMM=213;
break;

case 'J'://jaune
PWMC=0;
PWMJ=255;
PWMM=0;
break;

case 'N'://noir
PWMC=0;
PWMM=0;
PWMJ=0;
PWMN=255;
break;

case 'C': //blanche
PWMC=0;

Ecole Polytechnique Universitaire de Nice Sophia-Antipolis, Département électronique

PWMM=0;
PWMJ=0;
PWMB=255;
break;

case 'R': //rouge
PWMC=0;
PWMM=255;
PWMJ=0;
break;
case 'V': //vert
PWMC=255;
PWMJ=255;
PWMM=0;
break;

case 'B': //bleu
PWMC=255;
PWMJ=0;
PWMM=0;
break;

case 'G': //gris
PWMC=128;
PWMM=128;
PWMJ=128;
break;

case 'S': //rose
PWMC=0;
PWMM=255;
PWMJ=70;
break;

case 'M': //marron
PWMC=255;
PWMM=255;

Ecole Polytechnique Universitaire de Nice Sophia-Antipolis, Département électronique

PWMJ=255;
break;

case 'I': //violette
PWMC=153;
PWMM=255;
PWMJ=0;
break;

case 'D':
digitalWrite(enable,LOW);
for(int x = 0; x < PWMC; x++) { //tube bleu digitalWrite(Pas2,HIGH);
digitalWrite(Pas3,HIGH);
digitalWrite(Pas4,HIGH);
digitalWrite(Pas5,HIGH);

digitalWrite(Pas1,HIGH);
delayMicroseconds(50);
digitalWrite(Pas1,LOW);
delay(4);
}

for(int x = 0; x < PWMM; x++) { //tube rouge digitalWrite(Pas2,HIGH);
digitalWrite(Pas1,HIGH);
digitalWrite(Pas4,HIGH);
digitalWrite(Pas5,HIGH);

digitalWrite(Pas3,HIGH);
delayMicroseconds(50);
digitalWrite(Pas3,LOW);
delay(4); }

for(int x = 0; x < PWMJ; x++) { //tube jaune digitalWrite(Pas1,HIGH); //met le moteur à l'arret digitalWrite(Pas3,HIGH);

Ecole Polytechnique Universitaire de Nice Sophia-Antipolis, Département électronique

digitalWrite(Pas4,HIGH);
digitalWrite(Pas5,HIGH);

digitalWrite(Pas2,HIGH);
delayMicroseconds(50);
digitalWrite(Pas2,LOW);
delay(4); }

for(int x = 0; x < PWMN; x++) { //tube noir digitalWrite(Pas2,HIGH);
digitalWrite(Pas3,HIGH);
digitalWrite(Pas1,HIGH);
digitalWrite(Pas5,HIGH);

digitalWrite(Pas4,HIGH);
delayMicroseconds(50);
digitalWrite(Pas4,LOW);
delay(4); }
PWMN=0;

for(int x = 0; x < PWMB; x++) { //tube blanc digitalWrite(Pas2,HIGH);
digitalWrite(Pas3,HIGH);
digitalWrite(Pas4,HIGH);
digitalWrite(Pas1,HIGH);

digitalWrite(Pas5,HIGH);
delayMicroseconds(50);
digitalWrite(Pas5,LOW);
delay(4); }
PWMB=0;

digitalWrite(enable,HIGH); break;
}
}

Ecole Polytechnique Universitaire de Nice Sophia-Antipolis, Département électronique

////LED/////
analogWrite(LED1, PWMC);
analogWrite(LED2, PWMM);
analogWrite(LED3, PWMJ);
}

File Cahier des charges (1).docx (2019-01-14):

Queffeulou Jade le 10/12/2018

Turle Margaux

Projet Arduino

Make your Color

Nous avons eu l’idée pour notre projet Arduino de mettre en place une machine qui permettrait de créer différentes couleurs à l’aide des couleurs primaires (rouge, bleu et jaune) et du noir et blanc. Le principe est de choisir une des couleurs proposées sur un téléphone relié par Bluetooth à la machine et ensuite recevoir dans une palette la ou les couleurs voulues.

Ce projet peut être en particulier destiné à des écoles maternelles ou des centre aérés.

Les couleurs créées avec cette machine :

Le orange (mélange de rouge et de jaune)

Le violet (mélange de bleu et de rouge)

Le vert (mélange de jaune et bleu)

Le marron (mélange de rouge, jaune et bleu)

Le rose (rouge et blanc)

Le gris (noir et blanc)

Il sera également possible d’éclaircir (respectivement assombrir) les couleurs, en ajoutant au mélange la couleur blanche (respectivement noire).

La liste du matériel nécessaire :

- 5 moteurs pas à pas
- 5 driver 4988
- Une puce Bluetooth
- Un boitier modélisé sur inventor
- 5 seringues en plastique
- De la peinture
- Des palettes
- Des pinceaux

Répartition des tâches :

Margaux : construction de la machine

Jade : codes informatiques

Ensemble : branchements électroniques, soudure

Bien entendu les rôles ne sont pas fixes, chacune expérimentera tous les rôles pour en tirer le plus de connaissances possibles et permettre d’avancer plus rapide.

Nous trouverons judicieux de faire les branchements ensemble afin d’éviter toutes erreurs de branchements.

Diagramme de gantt :


Les programmes à réaliser :

- Connexion Bluetooth HC-06
- Moteur pas à pas
- Choix des couleurs à réaliser via les indicators Bluetooth

Moteur pas à pas :

4 fils moteur bipolaire

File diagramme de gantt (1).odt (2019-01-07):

Diagramme de Gantt

Légende :

J : Jade

M : Margaux

JM : Jade et Margaux


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
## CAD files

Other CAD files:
Ressources/Pièce1.ipt
Ressources/Pièce2.ipt
Ressources/socle.ipt

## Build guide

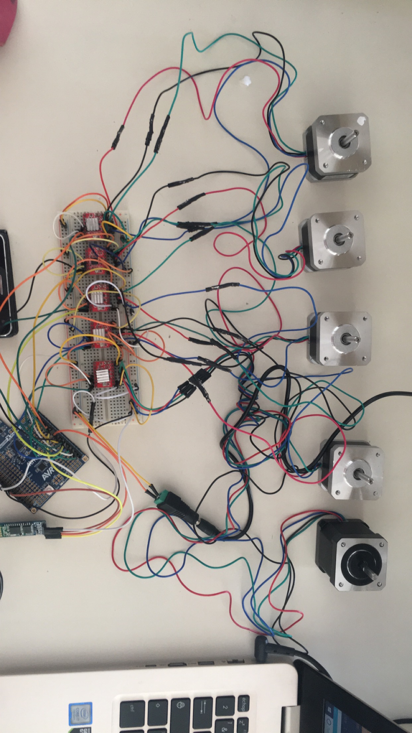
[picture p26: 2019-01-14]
Ressources/montage 5 moteurs.JPG

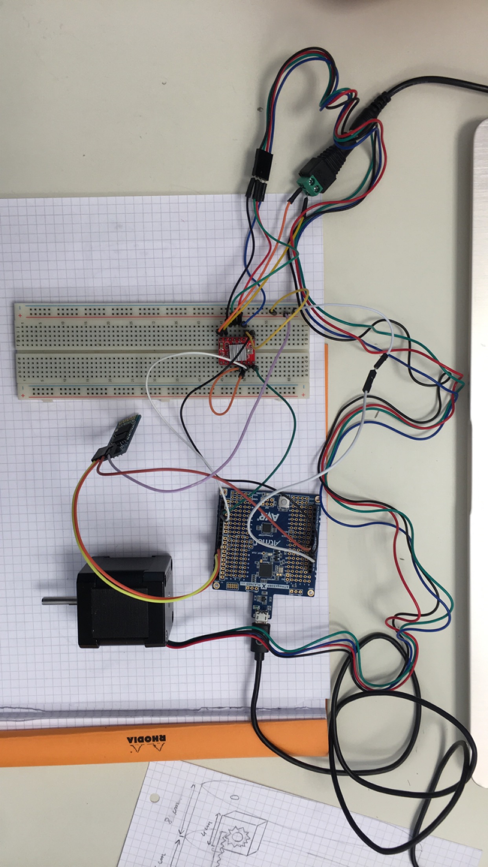
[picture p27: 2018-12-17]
Ressources/Montage avec un moteur pas à pas.JPG
